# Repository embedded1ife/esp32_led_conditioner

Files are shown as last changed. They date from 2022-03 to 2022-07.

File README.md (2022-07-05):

# Overview
This is one of those projects where it was a "problem" that I created. I decided that, after years of risking my life putting up Christmas lights, I was done. No, not done with Christmas lights, just the cycle. After taking inspiration from [The Hook Up](https://www.youtube.com/channel/UC2gyzKcHbYfqoXA5xbyGXtQ), and [DrZzs](https://www.youtube.com/c/DrZzs), I decided to install LED strips in a way that when they are off, you couldn't tell they were there. Where I deviated from those two installs was the need to wire each strip back to a central point. I wanted a decentralized solution that only required each strip have access to 120V, and the control would come via WiFi.

<image src="images/close_up_gutter.jpg" width="40%">&nbsp;&nbsp;&nbsp;&nbsp;
<image src="images/wall_mounted.jpg" width="40%">

# Details

Starting with the end goal: a device that is compatible with [WLED](https://kno.wled.ge/), has integrated WiFi (required for my decentralized configuration), and is small enough to fit inside a IP68(weatherproof) box for those lawn ornaments. I landed on the ESP32 in a NodeMCU configuration. From there the only thing that was lacking was a way to interface the ESP32 to the LED strips/strings. To solve this problem I designed a board using [KiCAD](https://www.kicad.org/).

## Requirements for board:
- Interface with an ESP32 \([Amazon](https://www.amazon.com/gp/product/B086MJGFVV), [AliExpress](https://www.aliexpress.com/item/1005001757645011.html)\)
- Provide connection for bare wire, or barrel jack (for interior use such as kitchen cabinets), from supply
- Provide connection for bare wire to LED strips
- Provide some voltage and current protection
- Support both 5V and 12V LEDs
- For teh 12V LEDs step down input voltage to a level that the LDO on the ESP32 NodeMCU can tolerate (5V)
  - The voltage regulator has the ability to run at 100% duty cycle making the board 5V and 12V compatible
- Step up the data line to the LEDs from 3.3V to 5V
- All fit inside a [IP68 Box](https://www.amazon.com/gp/product/B07TGHYQF4)

# Materials

<image src="images/pcb_assembled.jpg" width="40%">&nbsp;&nbsp;&nbsp;&nbsp;
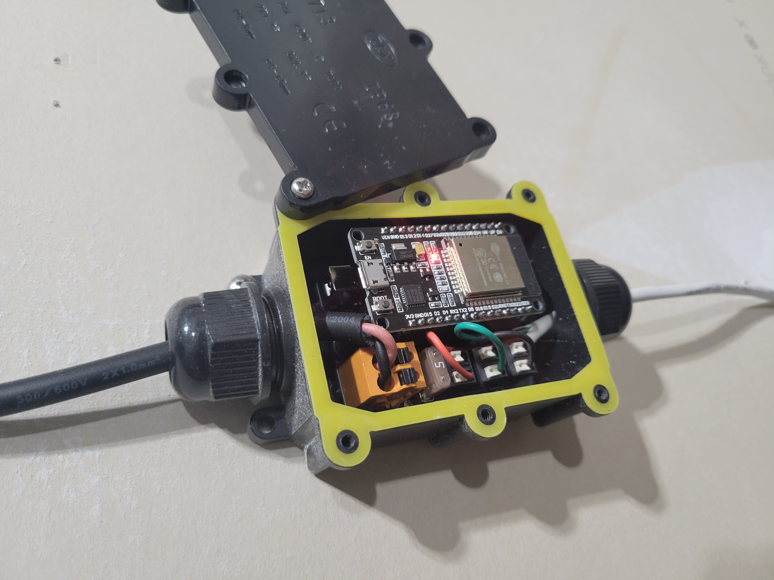
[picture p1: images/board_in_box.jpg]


## Board
- [PCB](https://oshpark.com/shared_projects/z9dy7YqV)
- [Components](bom.csv) from [Digikey](https://www.digikey.com/)

## ESP32
- [Amazon](https://www.amazon.com/gp/product/B086MJGFVV) or
- [AliExpress](https://www.aliexpress.com/item/1005001757645011.html)

## LED Strips
- [IP65 WS2815 12V](https://www.amazon.com/BTF-LIGHTING-Upgraded-Individually-Addressable-Non-Waterproof/dp/B07LG6KQ55)
  - I picked the WS2815 due to it being a 12V strip and thus reducing the need for power injection

## Hardware
- [IP68 Box](https://www.amazon.com/gp/product/B07TGHYQF4)
- [V-Shaped Channel](https://www.amazon.com/gp/product/B07F6FKGPH) for under the gutters
- [Low Profile Channel](https://www.amazon.com/gp/product/B07KDSYLGG) for the flat surface around the garage

## Supply
- [60W IP67](https://www.amazon.com/gp/product/B07MZP9247)
  - You will want a supply that matches the LEDs voltage because the board just passes the supply voltage on to the LEDs

## ESP32 Firmware

For the firmware I use [WLED](https://kno.wled.ge/). If new to this I recommend starting [here](https://kno.wled.ge/basics/getting-started/).

# Steps
1. Order materials

2. Assemble board

<image src="images/sch.png" width="30%">

3. Plug ESP32 into carrier board and power up

4. [Flash ESP32 with WLED](https://kno.wled.ge/basics/install-binary/)

# Tips
- For the flat aluminum channel around the garage, with about 1/8" of the side of the channel exposed, I wanted it to blend in with the white trim. I ended up using some [self etching primer](https://www.lowes.com/pd/Rust-Oleum-Stops-Rust-Flat-Gray-Spray-Primer-Actual-Net-Contents-12-oz/3728805), and white spray paint.
- After a year of having them up I had a problem where one strip would fade out 50% of the way down the strip, and the other the last 10% of the strip would not turn on. The problem ended up being that I did not protect the cut ends of the led strip and weather had caused them to short out. The image below is of my fix but you can see the chared remains from what happened.

<image src="images/burn_50_90.jpg" width="30%">

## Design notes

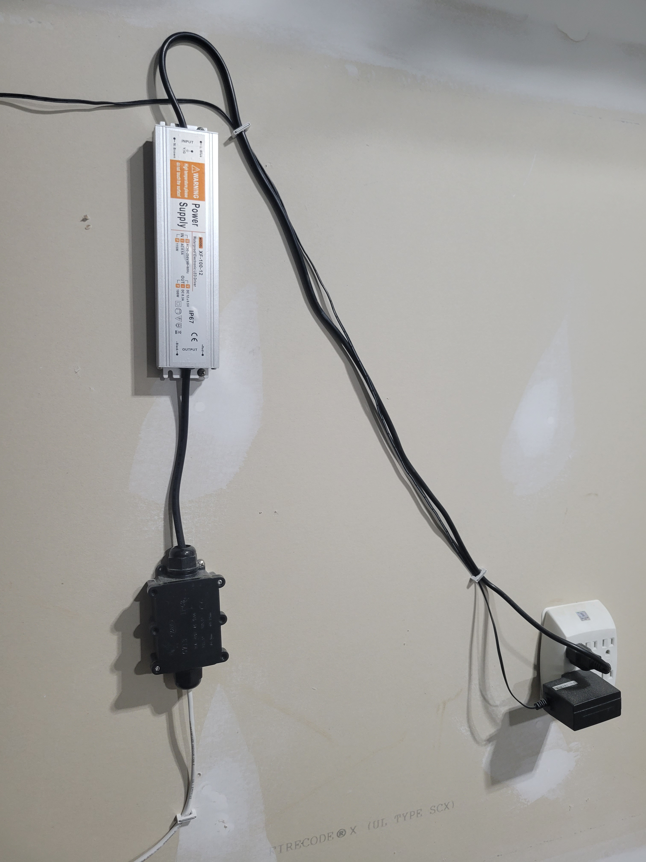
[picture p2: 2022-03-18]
images/wall_mounted.jpg

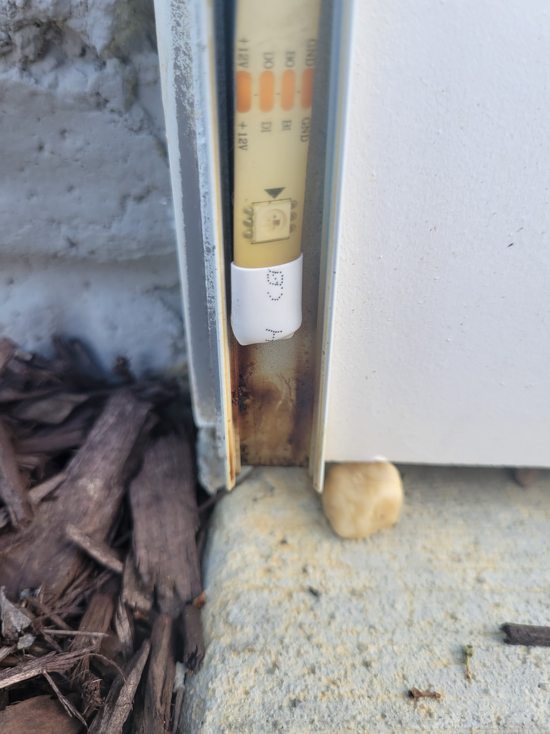
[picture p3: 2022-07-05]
images/burn_50_90.jpg

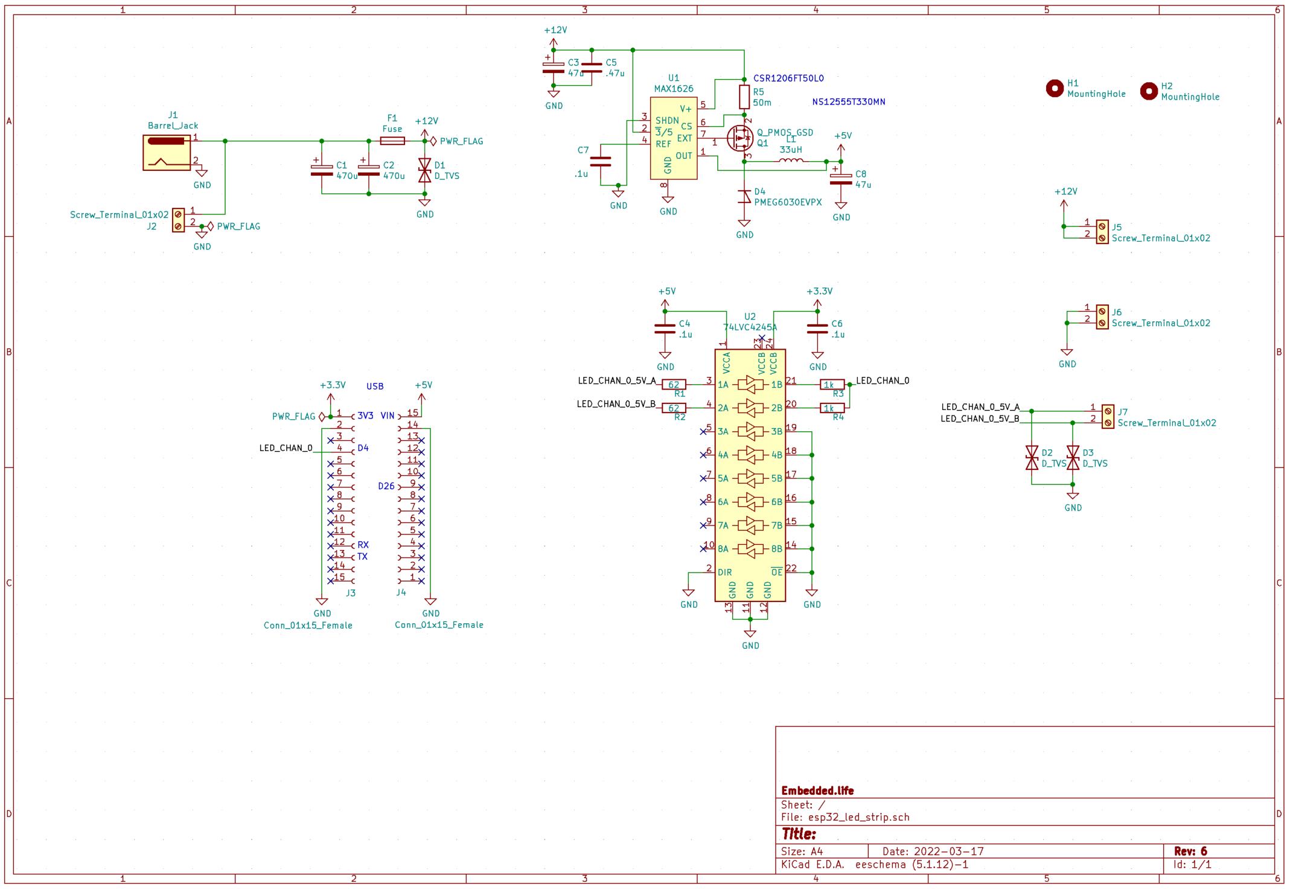
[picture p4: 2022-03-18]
images/sch.png

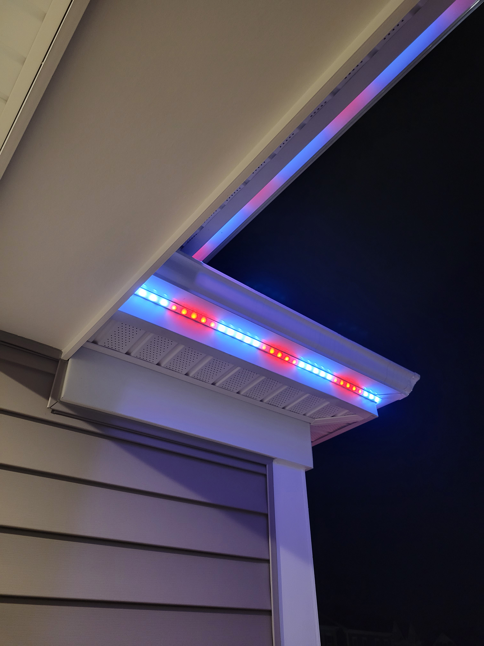
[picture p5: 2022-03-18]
images/close_up_gutter.jpg

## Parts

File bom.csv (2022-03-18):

Qty | Manufacture Part Number | Digikey Part Number | Description
1 | 1330180000 | 281-3995-ND | TERM BLK 2POS TOP ENTRY 5MM PCB
1 | 0297005.U | F6075-ND | FUSE AUTO 5A 32VDC BLADE MINI
3 | 1825960000 | 281-2124-ND | TERM BLK 2POS TOP ENTRY 5MM PCB
2 | 25PK470MEFC8X11.5 | 1189-1733-ND | CAP ALUM 470UF 20% 25V RADIAL
4 | PPPC151LFBN-RC | S7048-ND | CONN HDR 15POS 0.1 GOLD PCB
2 | A750EK476M1EAAE040 | 399-13665-ND | CAP ALUM POLY 47UF 20% 25V T/H
1 | ETQ-P5M680YFM | 10-ETQ-P5M680YFMCT-ND | FIXED IND 66UH 2.3A 276.1MOHM SM
2 | D5V0L1B2WS-7 | D5V0L1B2WS-7DICT-ND | TVS DIODE 5VWM 14VC SOD323
1 | TV04A120JB-G | 641-1235-1-ND | TVS DIODE 12VWM 19.9VC SMA
1 | PMEG6030EVPX | 1727-1349-1-ND | DIODE SCHOTTKY 60V 3A SOD128
1 | MAX1626ESA+T | MAX1626ESA+TCT-ND | IC REG CTRLR BUCK 8SOIC
1 | SN74LVCC3245ANSR | 296-17208-1-ND | IC TRNSLTR BIDIRECTIONAL 24SO
1 | CL21B474KAFNNNE | 1276-1074-1-ND | CAP CER 0.47UF 25V X7R 0805
1 | CSR1206FT50L0 | CSR1206FT50L0CT-ND | RES 0.05 OHM 1% 1/2W 1206
1 | AO3407A | 785-1006-1-ND | MOSFET P-CH 30V 4.3A SOT23-3L
1 | PJ-047AH | CP-047AH-ND | CONN PWR JACK 2X5.5MM SOLDER
2 | RC0805JR-071KL | 311-1.0KARCT-ND | RES 1K OHM 5% 1/8W 0805
2 | 3557 | 36-3557-ND | FUSE CLIP BLADE 500V 30A PCB
3 | 08055C104KAT2A | 478-1395-1-ND | CAP CER 0.1UF 50V X7R 0805
2 | RC0805FR-0762RL | 311-62.0CRCT-ND | RES 62 OHM 1% 1/8W 0805

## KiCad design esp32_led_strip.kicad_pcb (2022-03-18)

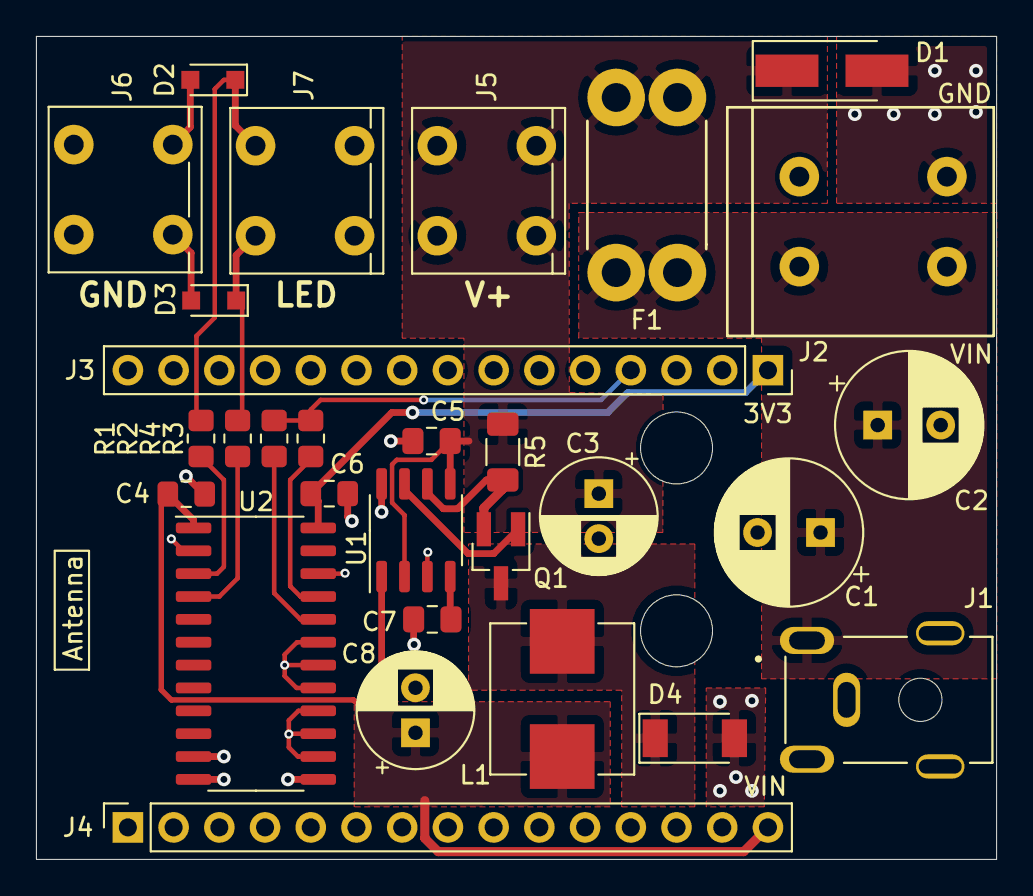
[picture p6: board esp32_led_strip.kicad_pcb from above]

Board: 2 copper layers, 53.3 x 45.7 mm, 31 parts (0 on the bottom side), 16 nets.

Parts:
C1, C2: 470u; CP_Radial_D8.0mm_P3.50mm
C3, C8: 47u; CP_Radial_D6.3mm_P2.50mm
C4, C6: .1u; C_0805_2012Metric_Pad1.15x1.40mm_HandSolder
C5: .47u; C_0805_2012Metric_Pad1.18x1.45mm_HandSolder
C7: .1u; C_0805_2012Metric_Pad1.18x1.45mm_HandSolder
D1: D_TVS; D_SMA_Handsoldering
D2, D3: D_TVS; D_SOD-323_HandSoldering
D4: ‎PMEG6030EVPX‎; D_SOD-128
F1: Fuse; 3557_mini_fuse
H1, H2: MountingHole; MountingHole_4mm
J1: Barrel_Jack; CUI_PJ-047AH
J2: Screw_Terminal_01x02; 1330180000
J3, J4: Conn_01x15_Female; PinSocket_1x15_P2.54mm_Vertical
J5, J6, J7: Screw_Terminal_01x02; 1825960000
L1: 33uH; ETQ-P5M470YFM
Q1: Q_PMOS_GSD; SOT-23_Handsoldering
R1, R2: 62; R_0805_2012Metric_Pad1.20x1.40mm_HandSolder
R3, R4: 1k; R_0805_2012Metric_Pad1.20x1.40mm_HandSolder
R5: 50m; R_1206_3216Metric_Pad1.30x1.75mm_HandSolder
U1: MAX1626; SO-8_3.9x4.9mm_P1.27mm
U2: 74LVC4245A; SO-24_5.3x15mm_P1.27mm

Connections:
+3V3: C6.1, J3.1, U2.24
+5V: C4.1, C8.1, J4.15, L1.2, U1.1, U2.1
+12V: C3.1, C5.1, D1.1, F1.1, J5.1, J5.2, R5.1, U1.2, U1.5
/LED_CHAN_0: J3.4, R3.1, R4.1
/LED_CHAN_0_5V_A: D2.1, J7.1, R1.2
/LED_CHAN_0_5V_B: D3.1, J7.2, R2.2
GND: C1.2, C2.2, C3.2, C4.2, C5.2, C6.2, C7.2, C8.2, D1.2, D2.2, D3.2, D4.2, J1.2, J2.2, J3.2, J4.14, J6.1, J6.2, U1.3, U1.8, U2.2, U2.11, U2.12, U2.13, U2.14, U2.15, U2.16, U2.17, U2.18, U2.19, U2.22
unnamed: C1.1, C2.1, F1.2, J1.1, J2.1
unnamed: C7.1, U1.4
unnamed: D4.1, L1.1, Q1.3
unnamed: Q1.1, U1.7
unnamed: Q1.2, R5.2, U1.6
unnamed: R1.1, U2.3
unnamed: R2.1, U2.4
unnamed: R3.2, U2.21
unnamed: R4.2, U2.20

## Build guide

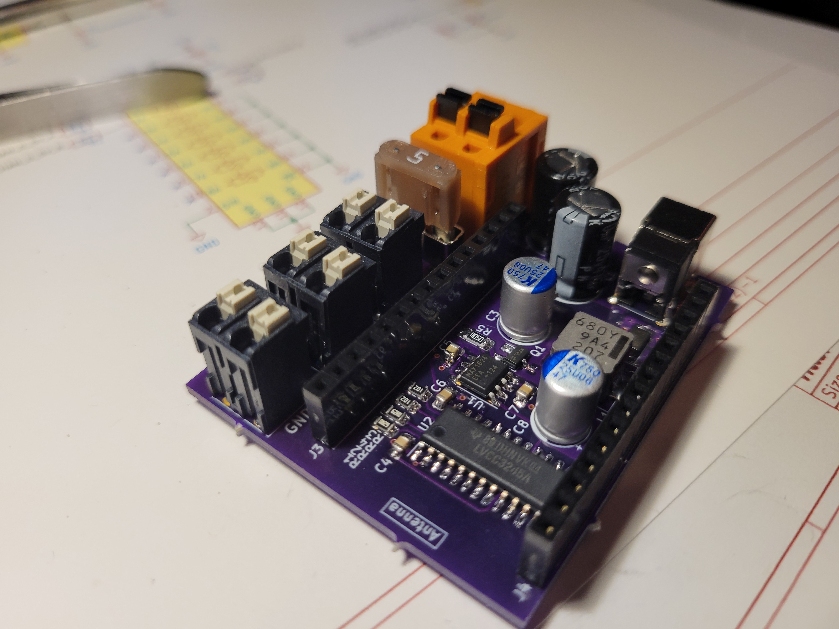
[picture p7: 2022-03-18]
images/pcb_assembled.jpg
